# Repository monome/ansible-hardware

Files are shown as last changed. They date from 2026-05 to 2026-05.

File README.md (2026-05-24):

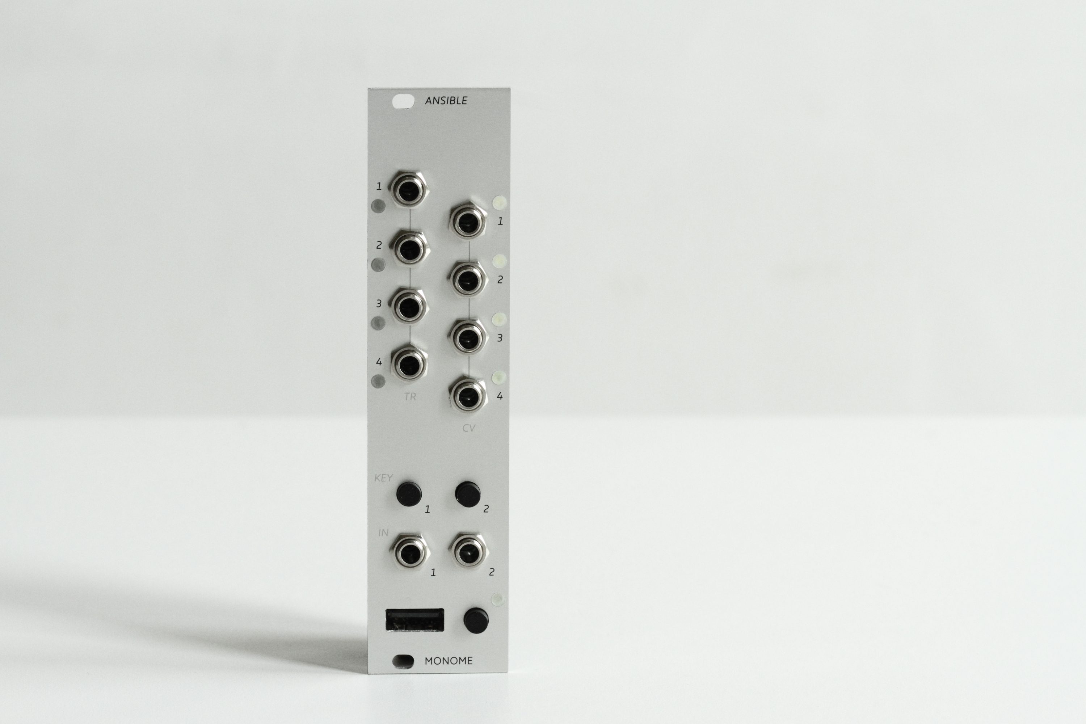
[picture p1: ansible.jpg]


# ansible hardware

eurorack module by https://monome.org

created by brian crabtree (bcrabtree@monome.org)

all circuits in eagle. can be imported to kicad.

firmware: https://github.com/monome/ansible

## notes

"ansible" is the top board, "runes" is the bottom board

## license

[cc-by-sa-3.0](https://creativecommons.org/licenses/by-sa/4.0/)

commerical use: send $10 per unit produced to tehn@nnnnnnnn.co via paypal

do not use the name "monome" or "ansible" in derivative works.

## warranty and support

we can provide neither

## thank you

everyone who helped this module live

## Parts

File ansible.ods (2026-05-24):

PN | Qty | Value | Package | Parts
450-1655-ND | 3 |  | B3F-10XX | S1, S2, S3
609-3221-ND | 1 |  | 2X10 | JP1
CL05B104KO5NNNC | 8 | 100n | C0402 | C1, C2, C4, C5, C7, C8, C9, C10
RC0402FR-0710KL | 19 | 10k | R0402 | R6, R7, R18, R19, R20, R21, R23, R39, R40, R41, R42, R43, R45, R48, R49, R70, R71, R72, R74
311-1.00KLRTR-ND‎ | 11 | 1k | R0402 | R1, R2, R3, R8, R11, R13, R14, R22, R44, R67, R75
GRM155R71H102KA01D | 3 | 1n | C0402 | C3, C6, C13
311-20.0KLRTR-ND | 8 | 20k | R0402 | R9, R10, R12, R15, R37, R38, R46, R47
311-30.0KLRTR-ND | 5 | 30k | R0402 | R4, R5, R16, R17, R73
296-1283-6-nd | 1 | TL074 | SO14 | IC1
BAS70-04TPMSCT-ND | 3 | BAS70-04 | SOT23 | D1, D3, D4
296-29037-1-ND | 1 | OPA4171A | SO14 | IC2
APT1608SYCK | 5 | ORANGE | CHIP-LED0603 | LED1, LED2, LED3, LED4, LED5
WM8672-ND | 1 | USB-VERT | MOLEX-USB | USB
S1012EC-10-ND | 1 | 1x10 | 1x10-header | X1
296-1282-6-ND | 1 | TL072 | SO8 | IC4
LTW-C191TS5 | 5 | WHITE | CHIP-LED0603 | LED6, LED7, LED8, LED10, LED11
WQP-PJ398S-BM | 10 | JACK | JACK | U1, U2, U3, U4, U5, U6, U7, U8, U9, U10

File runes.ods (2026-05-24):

Qty | Value | Package | Parts | Part Number
1 |  | 1X10 | JP3 | S7008-ND
1 |  | 2X10 | JP1 | S7078-ND
1 |  | 2X03 | JP2 | 609-3218-ND
3 | 0 | R0402 | R41, R42, R45 | RC0402JR-070RL
14 | 100n | C0402 | C1, C3, C7, C18, C21, C26, C30, C31, C41, C42, C46, C47, C50, C56 | CL05B104KO5NNNC
6 | 10k | R0402 | R3, R4, R6, R8, R10, R40 | RC0402FR-0710KL
6 | 10u | C1206/T | C4, C6, C22, C24, C28, C44 | 1276-1075-2-ND
1 | 12mhz | HC49UP | Y1 | ECS-120-18-5PX-TR
2 | 22p | C0402 | C19, C20 | C0402C220J4GACTU
3 | 2.2u | C0603 | C9, C48, C55 | 490-10731-2-ND
4 | 2.7n | C0402 | C8, C13, C14, C15 | GRM155R71H272KA01D
4 | 20k | R0402 | R5, R7, R9, R11 | 311-20.0KLRTR-ND
1 | 2510- | PAK100/2500-10 | X1 | ED1543-ND
8 | 33n | C0402 | C10, C12, C16, C17, C45, C52, C53, C54 | CL05B333KA5NNNC
2 | 39 | R0402 | R43, R44 | 311-39.0LRTR-ND
1 | 4.7u | C1206/T | C5 | F931C475KAA
2 | 4.7u | C0603 | C49, C51 | CL10A475KO8NNNC
1 | 470p | C0402 | C11 | UMK105B7471KV-F
2 | 47k | R0402 | R1, R2 | RC0402FR-0747KL
2 | AD5687R | TSSOP16 | U3, U4 | AD5687RBRUZ-RL7
1 | ADP3339 | SOT223 | U40 | ADP3339AKCZ-3.3-R7
1 | AT32UC3B064/0128/0256 | TQFP64-10X10 | U2 | AT32UC3B0512-A2UT
1 | BAS70-04 | SOT23 | U6 | BAS70-04TPMSCT-ND
1 | OKI-78SR | TO220V | IC2 | 811-2692-ND
2 | PTC-F0805-15V | F0805 | PF1, PF2 | 507-1805-2-ND
1 | TPS2021 | SO08 | U1 | TPS2021DR

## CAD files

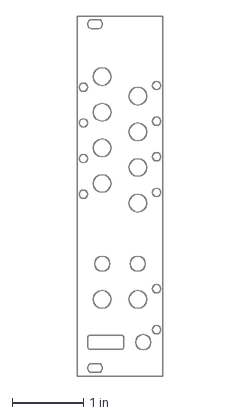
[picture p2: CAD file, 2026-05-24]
ansible.dxf
1.20 x 5.05 in

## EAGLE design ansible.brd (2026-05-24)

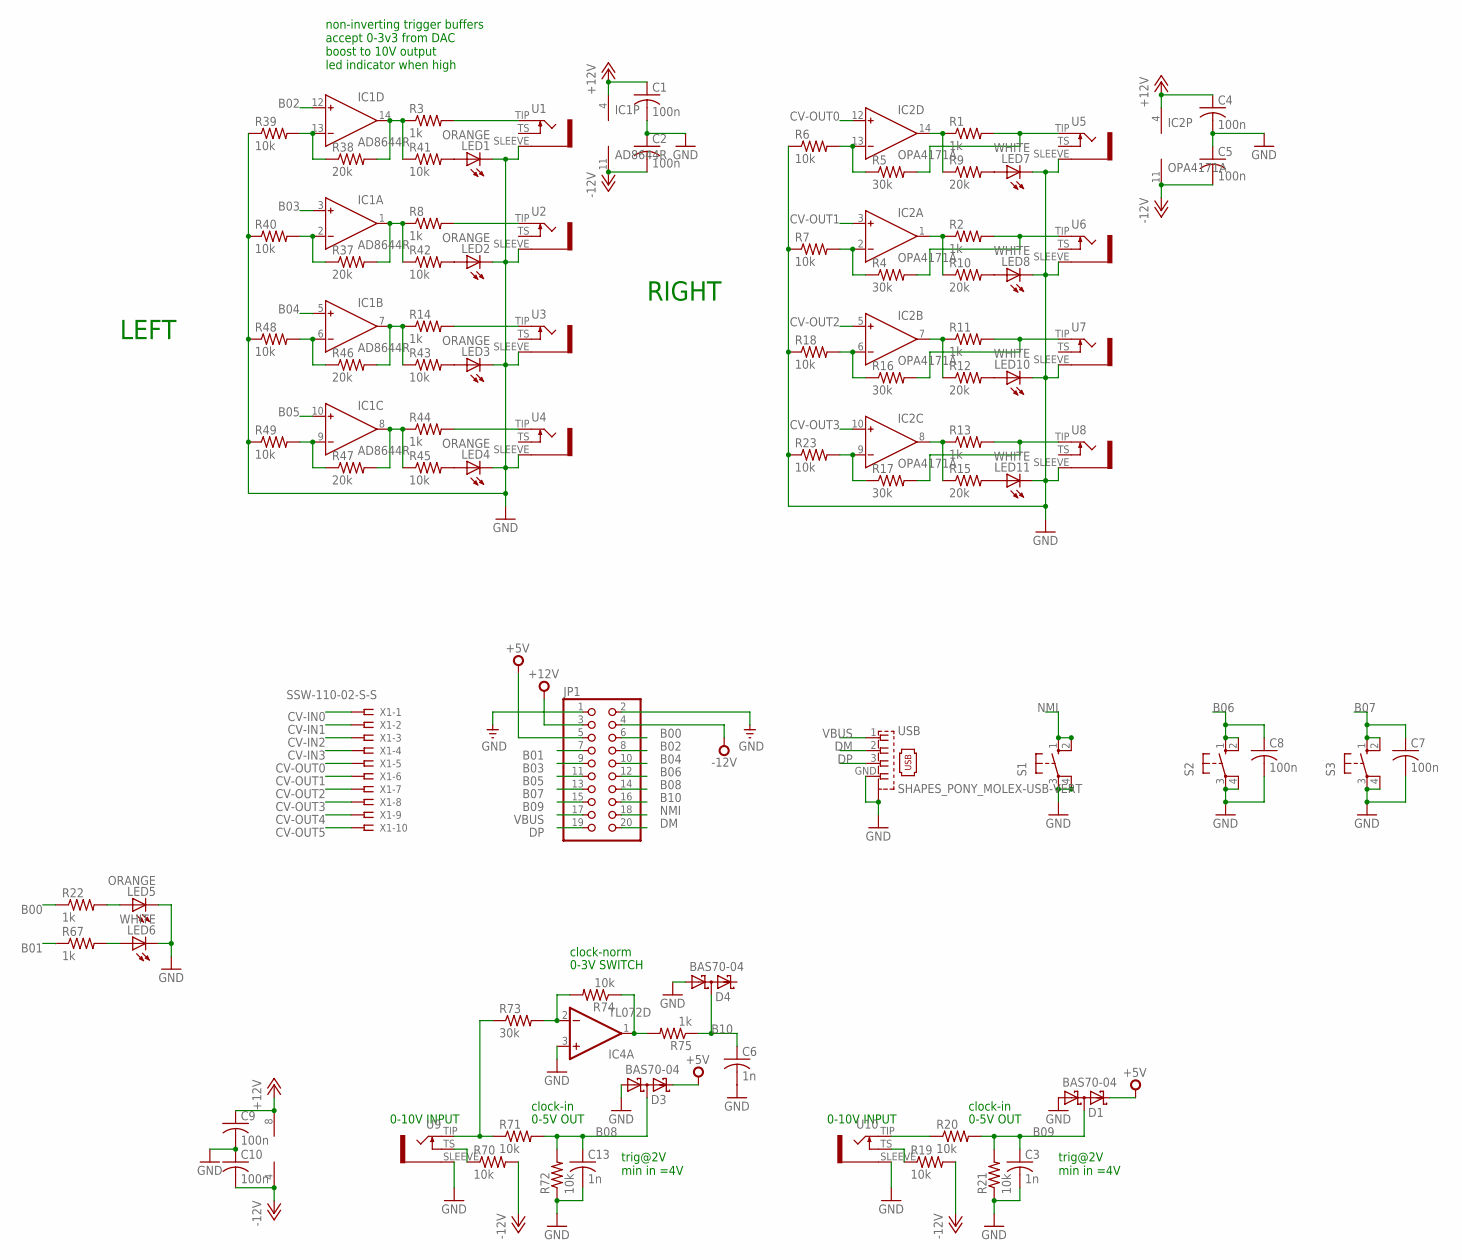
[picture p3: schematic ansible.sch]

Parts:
C1, C2, C4, C5, C7, C8, C9, C10: 100n; C0402
C3, C6, C13: 1n; C0402
D1, D3, D4: BAS70-04; SOT23
IC1: AD8644R; SO14
IC2: OPA4171A; SO14
IC4: TL072D; SO08
JP1: PINHD-2X10; 2X10
LED1, LED2, LED3, LED4, LED5: ORANGE; CHIP-LED0603
LED6, LED7, LED8, LED10, LED11: WHITE; CHIP-LED0603
R1, R2, R3, R8, R11, R13, R14, R22, R44, R67, R75: 1k; R0402
R4, R5, R16, R17, R73: 30k; R0402
R6, R7, R18, R19, R20, R21, R23, R39, R40, R41, R42, R43, R45, R48, R49, R70, R71, R72, R74: 10k; R0402
R9, R10, R12, R15, R37, R38, R46, R47: 20k; R0402
S1, S2, S3: 10-XX; B3F-10XX
U1, U2, U3, U4, U5, U6, U7, U8, U9, U10: WQP-PJ301M-12_JACK
USB: SHAPES_PONY_MOLEX-USB-VERT; SHAPES_PONY_MOLEX-USB
X1: SSW-110-02-S-S

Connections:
+5V: D1.2 (C2), D3.2 (C2), JP1.5
+12V: C1.1, C4.1, C9.1, IC1.4 (V+), IC2.4 (V+), IC4.8 (V+), JP1.3
-12V: C2.2, C5.2, C10.2, IC1.11 (V-), IC2.11 (V-), IC4.4 (V-), JP1.4, R19.2, R70.2
B00: JP1.6, R22.1
B01: JP1.7, R67.1
B02: IC1.12 (IN+), JP1.8
B03: IC1.3 (IN+), JP1.9
B04: IC1.5 (IN+), JP1.10
B05: IC1.10 (IN+), JP1.11
B06: C8.1, JP1.12, S2.1 (S), S2.2 (S1)
B07: C7.1, JP1.13, S3.1 (S), S3.2 (S1)
B08: C13.1, D3.3 (C1A2), JP1.14, R71.2, R72.2
B09: C3.1, D1.3 (C1A2), JP1.15, R20.2, R21.2
B10: C6.1, D4.3 (C1A2), JP1.16, R75.1
CV-IN0: X1.1
CV-IN1: X1.2
CV-IN2: X1.3
CV-IN3: X1.4
CV-OUT0: IC2.12 (IN+), X1.5
CV-OUT1: IC2.3 (IN+), X1.6
CV-OUT2: IC2.5 (IN+), X1.7
CV-OUT3: IC2.10 (IN+), X1.8
CV-OUT4: X1.9
CV-OUT5: X1.10
DM: JP1.20, USB.2
DP: JP1.19, USB.3
GND: C1.2, C2.1, C3.2, C4.2, C5.1, C6.2, C7.2, C8.2, C9.2, C10.1, C13.2, D1.1 (A1), D3.1 (A1), D4.1 (A1), IC4.3 (+IN), JP1.1, JP1.2, LED1.C, LED2.C, LED3.C, LED4.C, LED5.C, LED6.C, LED7.C, LED8.C, LED10.C, LED11.C, R6.1, R7.1, R18.1, R21.1, R23.1, R39.1, R40.1, R48.1, R49.1, R72.1, S1.3, S1.4 (P1), S2.3, S2.4 (P1), S3.3, S3.4 (P1), U1.SLEEVE, U2.SLEEVE, U3.SLEEVE, U4.SLEEVE, U5.SLEEVE, U6.SLEEVE, U7.SLEEVE, U8.SLEEVE, U9.SLEEVE, U10.SLEEVE, USB.GND, USB.M1 (S1), USB.M2 (S1), USB.M4 (S1)
N: IC4.1 (OUT), R74.1, R75.2
unnamed: IC4.2 (-IN), R73.2, R74.2
unnamed: IC1.14 (OUT), R3.1, R38.2, R41.1
unnamed: IC1.1 (OUT), R8.1, R37.2, R42.1
unnamed: IC1.7 (OUT), R14.1, R43.1, R46.2
unnamed: IC1.8 (OUT), R44.1, R45.1, R47.2
unnamed: R3.2, U1.TIP
unnamed: R8.2, U2.TIP
unnamed: R14.2, U3.TIP
unnamed: R44.2, U4.TIP
unnamed: R20.1, U10.TIP
unnamed: IC2.14 (OUT), R1.1, R9.1
unnamed: IC2.1 (OUT), R2.1, R10.1
unnamed: IC2.7 (OUT), R11.1, R12.1
unnamed: IC2.8 (OUT), R13.1, R15.1
unnamed: LED5.A, R22.2
unnamed: R13.2, R17.2, U8.TIP
unnamed: IC2.13 (IN-), R5.1, R6.2
unnamed: IC2.2 (IN-), R4.1, R7.2
unnamed: LED7.A, R9.2
unnamed: LED8.A, R10.2
unnamed: R70.1, U9.TS
unnamed: R19.1, U10.TS
unnamed: IC2.9 (IN-), R17.1, R23.2
unnamed: IC2.6 (IN-), R16.1, R18.2
unnamed: LED10.A, R12.2
unnamed: LED11.A, R15.2
unnamed: R1.2, R5.2, U5.TIP
unnamed: R2.2, R4.2, U6.TIP
unnamed: R11.2, R16.2, U7.TIP
unnamed: IC1.9 (IN-), R47.1, R49.2
unnamed: IC1.6 (IN-), R46.1, R48.2
unnamed: R71.1, R73.1, U9.TIP
unnamed: IC1.13 (IN-), R38.1, R39.2
unnamed: IC1.2 (IN-), R37.1, R40.2
unnamed: LED6.A, R67.2
unnamed: LED1.A, R41.2
unnamed: LED2.A, R42.2
unnamed: LED3.A, R43.2
unnamed: LED4.A, R45.2
NMI: JP1.18, S1.1 (S), S1.2 (S1)
VBUS: JP1.17, USB.1

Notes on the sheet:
0-10V INPUT
0-5V OUT
0-3V SWITCH
non-inverting trigger buffers accept 0-3v3 from DAC boost to 10V output led indicator when high
LEFT
RIGHT
clock-norm
clock-in
trig@2V min in =4V

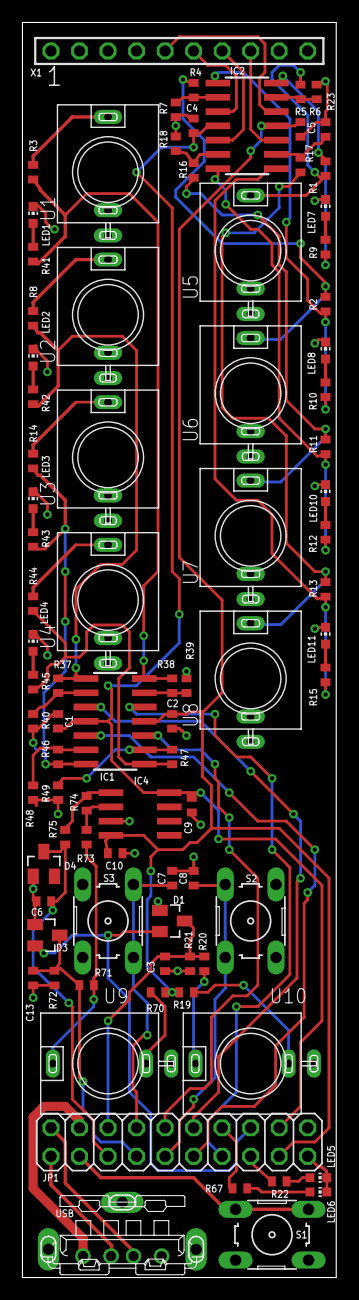
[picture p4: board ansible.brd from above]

Board: 2 copper layers, 27.9 x 111.8 mm, 86 parts (0 on the bottom side), 63 nets.

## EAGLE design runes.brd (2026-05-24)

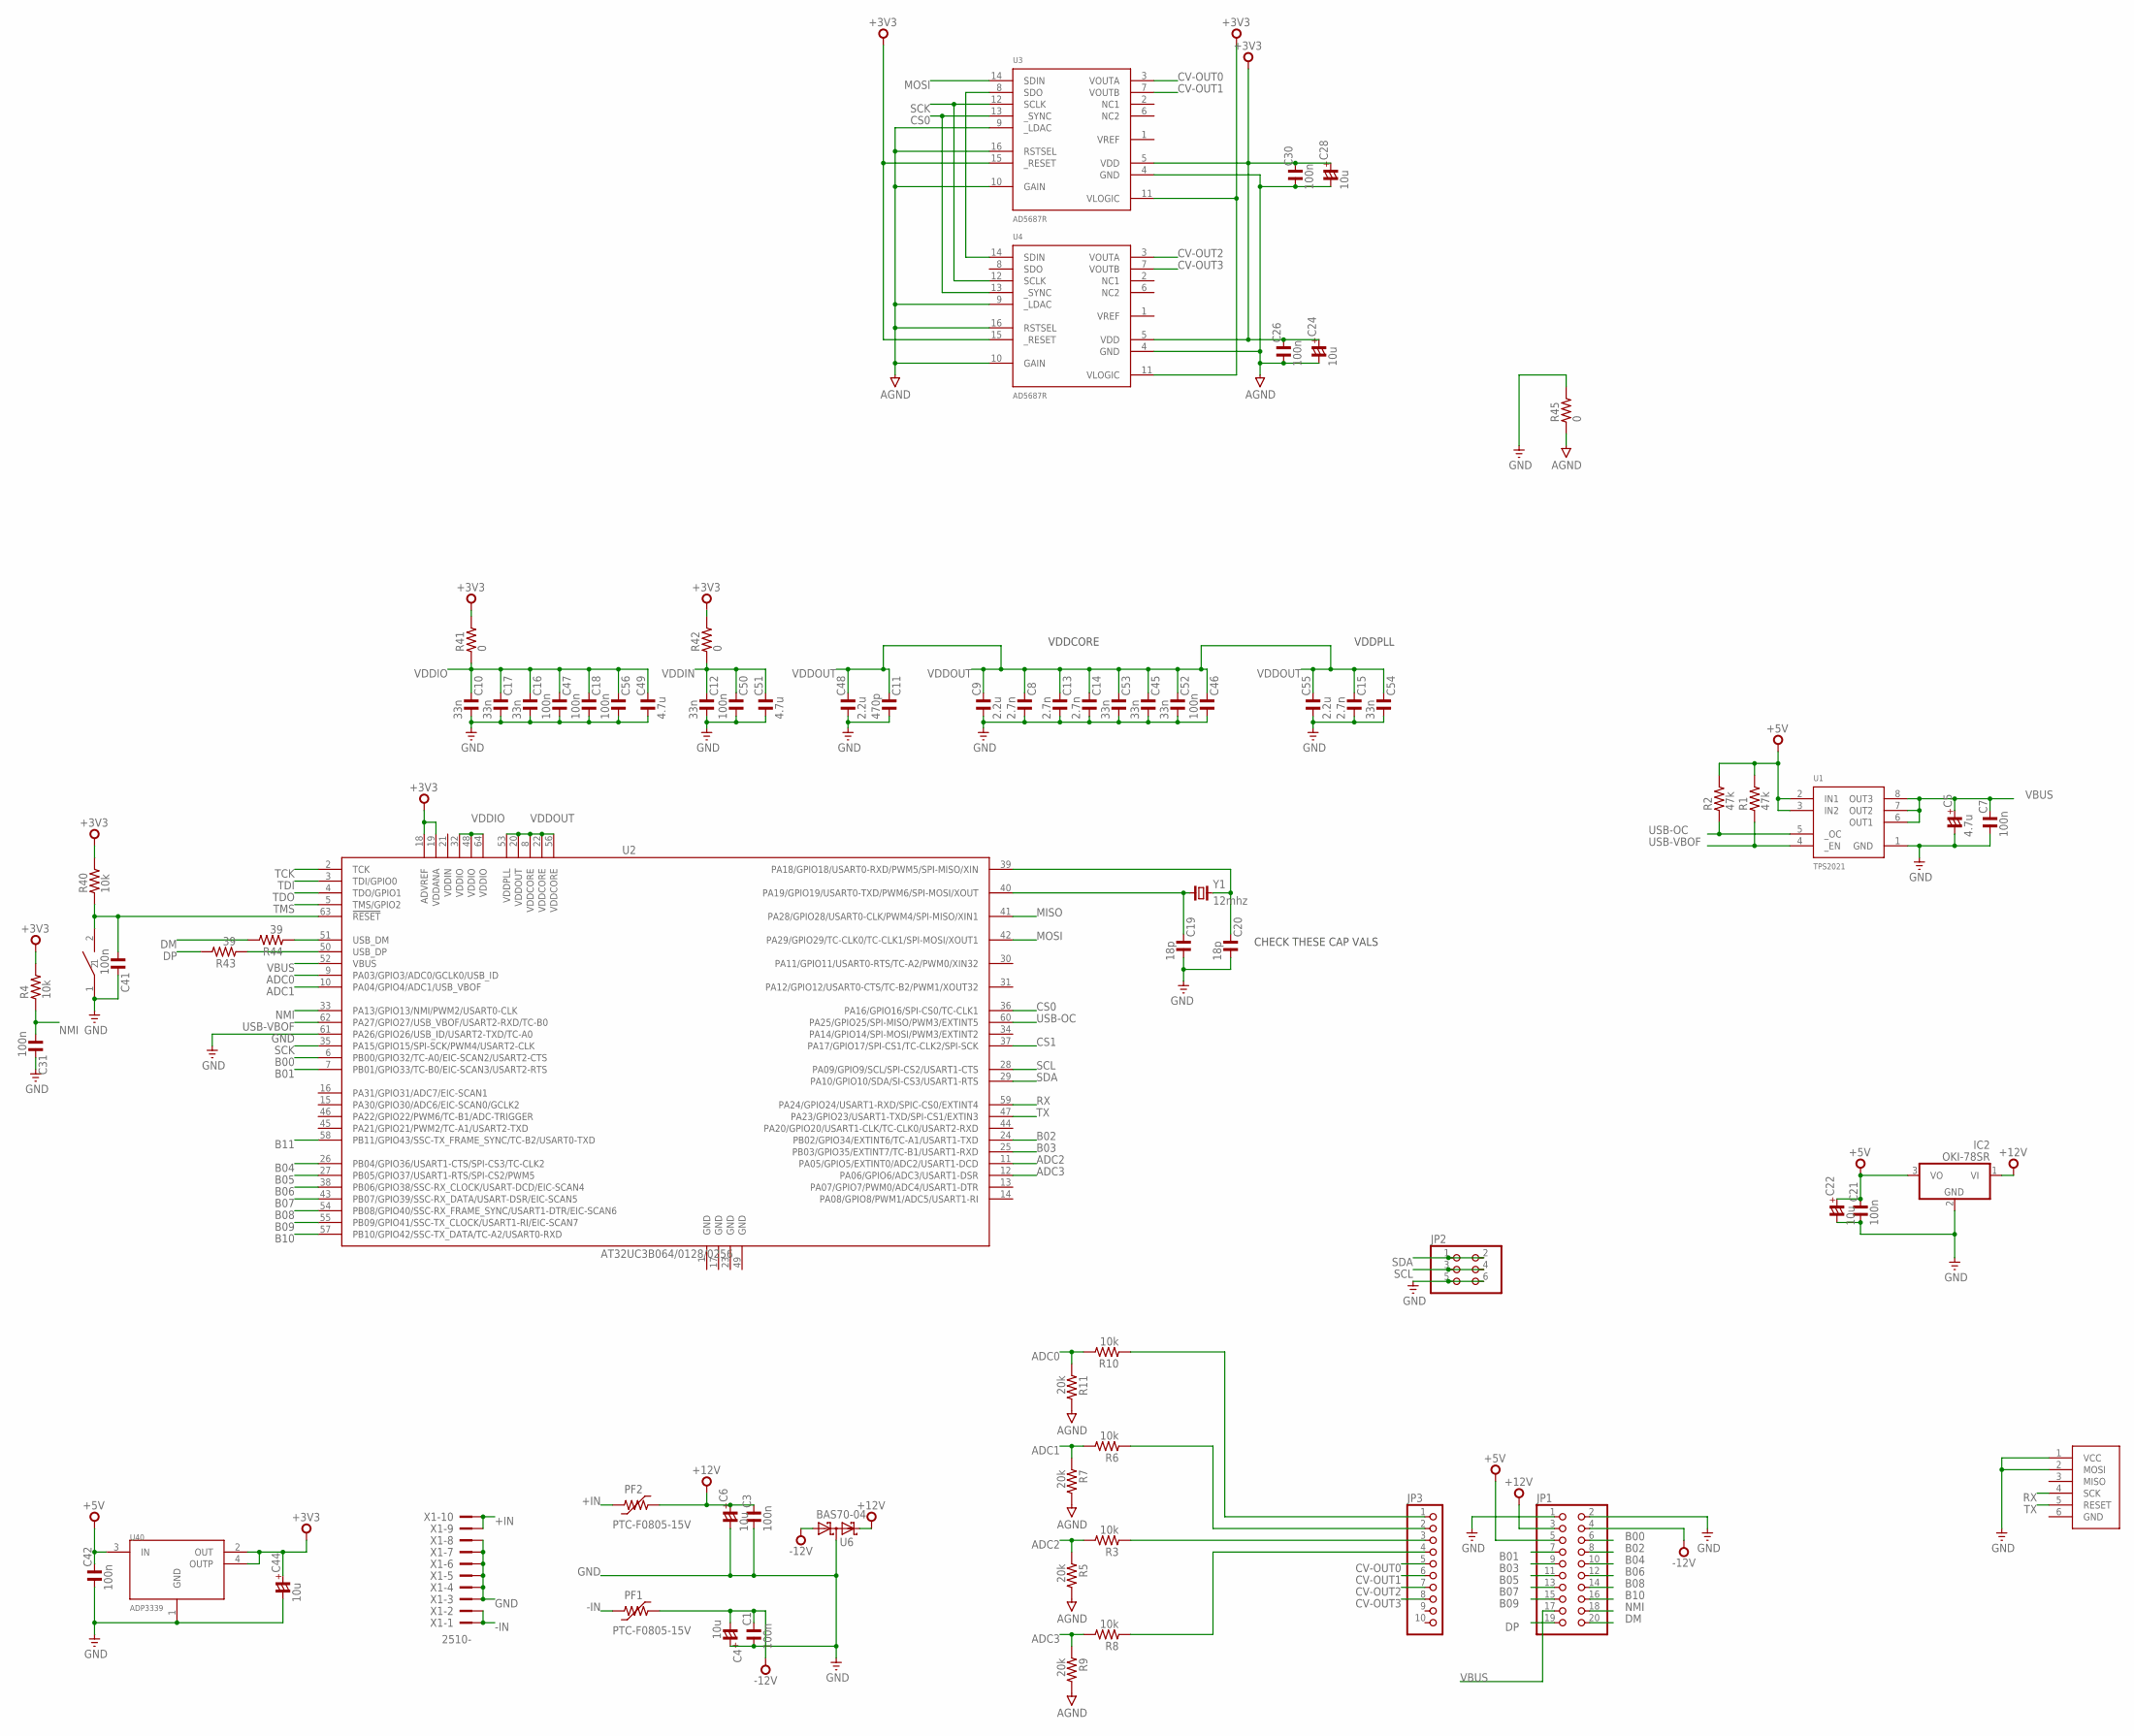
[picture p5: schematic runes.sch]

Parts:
C1, C3, C7, C18, C21, C26, C30, C31, C41, C42, C46, C47, C50, C56: 100n; C0402
C4, C6, C22, C24, C28, C44: 10u; C1206/T
C5: 4.7u; C1206/T
C8, C13, C14, C15: 2.7n; C0402
C9, C48, C55: 2.2u; C0603
C10, C12, C16, C17, C45, C52, C53, C54: 33n; C0402
C11: 470p; C0402
C19, C20: 18p; C0402
C49, C51: 4.7u; C0603
IC2: OKI-78SR; TO220V
J40: ISP-ROW
JP1: PINHD-2X10; 2X10
JP2: PINHD-2X3; 2X03
JP3: PINHD-1X10; 1X10
PF1, PF2: PTC-F0805-15V; F0805
R1, R2: 47k; R0402
R3, R4, R6, R8, R10, R40: 10k; R0402
R5, R7, R9, R11: 20k; R0402
R41, R42, R45: 0; R0402
R43, R44: 39; R0402
SW40: PANASONIC-EVQ
U1: TPS2021; SO08
U2: AT32UC3B064/0128/0256; TQFP64-10X10
U3, U4: AD5687R; TSSOP16
U6: BAS70-04; SOT23
U40: ADP3339; SOT223
X1: 2510-; PAK100/2500-10
Y1: 12mhz; HC49UP

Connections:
+3V3: C24.+, C26.2, C28.+, C30.2, C44.+, R4.2, R40.2, R41.2, R42.2, U2.18 (ADVREF), U2.19 (VDDANA), U3.5 (VDD), U3.11 (VLOGIC), U3.15 (_RESET), U4.5 (VDD), U4.11 (VLOGIC), U4.15 (_RESET), U40.2 (OUT), U40.4 (OUTP)
+5V: C21.2, C22.+, C42.2, IC2.3 (VO), JP1.5, R1.2, R2.2, U1.2 (IN1), U1.3 (IN2), U40.3 (IN)
+12V: C3.2, C6.+, IC2.1 (VI), JP1.3, PF2.2, U6.2 (C2)
+IN: PF2.1, X1.9, X1.10
-12V: C1.2, C4.-, JP1.4, PF1.2, U6.1 (A1)
-IN: PF1.1, X1.1, X1.2
ADC0: R10.2, R11.1, U2.9 (PA03/GPIO3/ADC0/GCLK0/USB_ID)
ADC1: R6.2, R7.1, U2.10 (PA04/GPIO4/ADC1/USB_VBOF)
ADC2: R3.2, R5.1, U2.11 (PA05/GPIO5/EXTINT0/ADC2/USART1-DCD)
ADC3: R8.2, R9.1, U2.12 (PA06/GPIO6/ADC3/USART1-DSR)
AGND: C24.-, C26.1, C28.-, C30.1, R5.2, R7.2, R9.2, R11.2, R45.1, U3.4 (GND), U3.9 (_LDAC), U3.10 (GAIN), U3.16 (RSTSEL), U4.4 (GND), U4.9 (_LDAC), U4.10 (GAIN), U4.16 (RSTSEL)
B00: JP1.6, U2.6 (PB00/GPIO32/TC-A0/EIC-SCAN2/USART2-CTS)
B01: JP1.7, U2.7 (PB01/GPIO33/TC-B0/EIC-SCAN3/USART2-RTS)
B02: JP1.8, U2.24 (PB02/GPIO34/EXTINT6/TC-A1/USART1-TXD)
B03: JP1.9, U2.25 (PB03/GPIO35/EXTINT7/TC-B1/USART1-RXD)
B04: JP1.10, U2.26 (PB04/GPIO36/USART1-CTS/SPI-CS3/TC-CLK2)
B05: JP1.11, U2.27 (PB05/GPIO37/USART1-RTS/SPI-CS2/PWM5)
B06: JP1.12, U2.38 (PB06/GPIO38/SSC-RX_CLOCK/USART-DCD/EIC-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)
B07: JP1.13, U2.43 (PB07/GPIO39/SSC-RX_DATA/USART-DSR/EIC-S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)
B08: JP1.14, U2.54 (PB08/GPIO40/SSC-RX_FRAME_SYNC/USART1-DT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)
B09: JP1.15, U2.55 (PB09/GPIO41/SSC-TX_CLOCK/USART1-RI/EIC-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)
B10: JP1.16, U2.57 (PB10/GPIO42/SSC-TX_DATA/TC-A2/USART0-RXD)
B11: U2.58 (PB11/GPIO43/SSC-TX_FRAME_SYNC/TC-B2/USA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)
CS0: U2.36 (PA16/GPIO16/SPI-CS0/TC-CLK1), U3.13 (_SYNC), U4.13 (_SYNC)
CS1: U2.37 (PA17/GPIO17/SPI-CS1/TC-CLK2/SPI-SCK)
CV-OUT0: JP3.5, U3.3 (VOUTA)
CV-OUT1: JP3.6, U3.7 (VOUTB)
CV-OUT2: JP3.7, U4.3 (VOUTA)
CV-OUT3: JP3.8, U4.7 (VOUTB)
DM: JP1.20, R44.2
DP: JP1.19, R43.2
GND: C1.1, C3.1, C4.+, C5.-, C6.-, C7.1, C8.1, C9.1, C10.1, C11.1, C12.1, C13.1, C14.1, C15.1, C16.1, C17.1, C18.1, C19.1, C20.1, C21.1, C22.-, C31.2, C41.2, C42.1, C44.-, C45.1, C46.1, C47.1, C48.1, C49.1, C50.1, C51.1, C52.1, C53.1, C54.1, C55.1, C56.1, IC2.2 (GND), J40.1 (VCC), J40.2 (MOSI), JP1.1, JP1.2, JP2.5, JP2.6, R45.2, SW40.1, U1.1 (GND), U2.1 (GND), U2.17 (GND), U2.23 (GND), U2.49 (GND), U2.61 (PA26/GPIO26/USB_ID/USART2-TXD/TC-A0), U6.3 (C1A2), U40.1 (GND), X1.3, X1.4, X1.5, X1.6, X1.7, X1.8
MISO: U2.41 (PA28/GPIO28/USART0-CLK/PWM4/SPI-MISO/XI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)
MOSI: U2.42 (PA29/GPIO29/TC-CLK0/TC-CLK1/SPI-MOSI/XO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), U3.14 (SDIN)
unnamed: R44.1, U2.51 (USB_DM)
unnamed: R43.1, U2.50 (USB_DP)
unnamed: JP3.1, R10.1
unnamed: U3.8 (SDO), U4.14 (SDIN)
unnamed: JP3.2, R6.1
unnamed: JP3.3, R3.1
unnamed: JP3.4, R8.1
unnamed: C20.2, U2.39 (PA18/GPIO18/USART0-RXD/PWM5/SPI-MISO/XIN), Y1.2
unnamed: C19.2, U2.40 (PA19/GPIO19/USART0-TXD/PWM6/SPI-MOSI/XO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), Y1.1
NMI: C31.1, JP1.18, R4.1, U2.33 (PA13/GPIO13/NMI/PWM2/USART0-CLK)
RESET: C41.1, R40.1, SW40.2, U2.63 (!RESET)
RX: J40.4 (SCK), U2.59 (PA24/GPIO24/USART1-RXD/SPIC-CS0/EXTINT4)
SCK: U2.35 (PA15/GPIO15/SPI-SCK/PWM4/USART2-CLK), U3.12 (SCLK), U4.12 (SCLK)
SCL: JP2.3, JP2.4, U2.28 (PA09/GPIO9/SCL/SPI-CS2/USART1-CTS)
SDA: JP2.1, JP2.2, U2.29 (PA10/GPIO10/SDA/SI-CS3/USART1-RTS)
TCK: U2.2 (TCK)
TDI: U2.3 (TDI/GPIO0)
TDO: U2.4 (TDO/GPIO1)
TMS: U2.5 (TMS/GPIO2)
TX: J40.5 (RESET), U2.47 (PA23/GPIO23/USART1-TXD/SPI-CS1/EXTIN3)
USB-OC: R2.1, U1.5 (_OC), U2.60 (PA25/GPIO25/SPI-MISO/PWM3/EXTINT5)
USB-VBOF: R1.1, U1.4 (_EN), U2.62 (PA27/GPIO27/USB_VBOF/USART2-RXD/TC-B0)
VBUS: C5.+, C7.2, JP1.17, U1.6 (OUT1), U1.7 (OUT2), U1.8 (OUT3), U2.52 (VBUS)
VDDIN: C12.2, C50.2, C51.2, R42.1, U2.21 (VDDIN)
VDDIO: C10.2, C16.2, C17.2, C18.2, C47.2, C49.2, C56.2, R41.1, U2.32 (VDDIO), U2.48 (VDDIO), U2.64 (VDDIO)
VDDOUT: C8.2, C9.2, C11.2, C13.2, C14.2, C15.2, C45.2, C46.2, C48.2, C52.2, C53.2, C54.2, C55.2, U2.8 (VDDCORE), U2.20 (VDDOUT), U2.22 (VDDCORE), U2.53 (VDDPLL), U2.56 (VDDCORE)

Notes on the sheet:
CHECK THESE CAP VALS
VDDCORE
VDDPLL

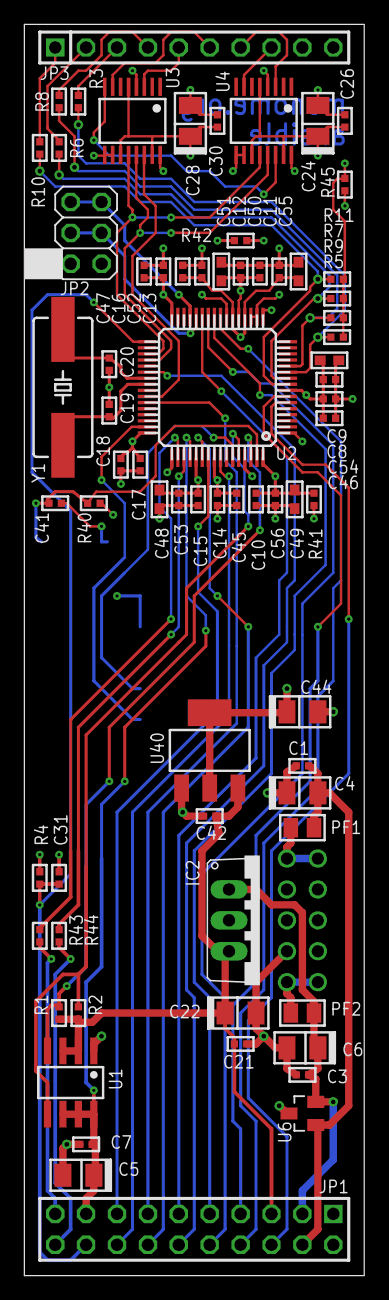
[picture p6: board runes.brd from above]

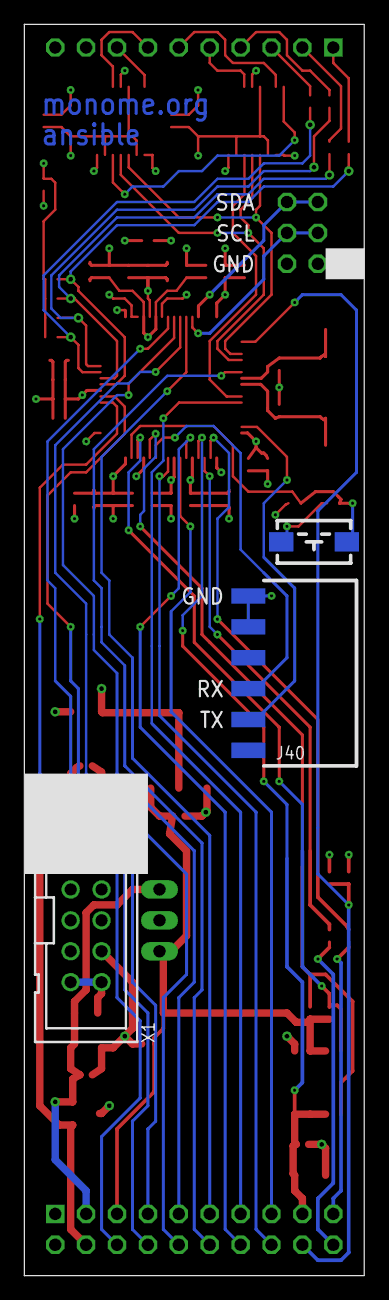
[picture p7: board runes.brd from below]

Board: 4 copper layers, 27.9 x 102.9 mm, 74 parts (3 on the bottom side), 53 nets.

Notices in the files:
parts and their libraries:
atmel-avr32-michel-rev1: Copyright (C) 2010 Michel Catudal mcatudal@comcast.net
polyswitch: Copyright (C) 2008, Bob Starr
